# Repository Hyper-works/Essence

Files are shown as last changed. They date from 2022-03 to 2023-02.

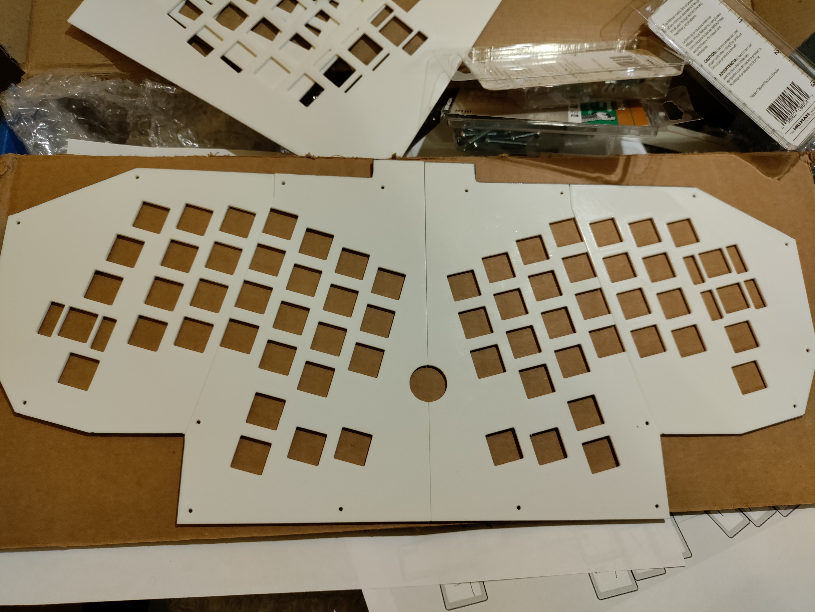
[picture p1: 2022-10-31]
IMG_20220821_130926.jpg

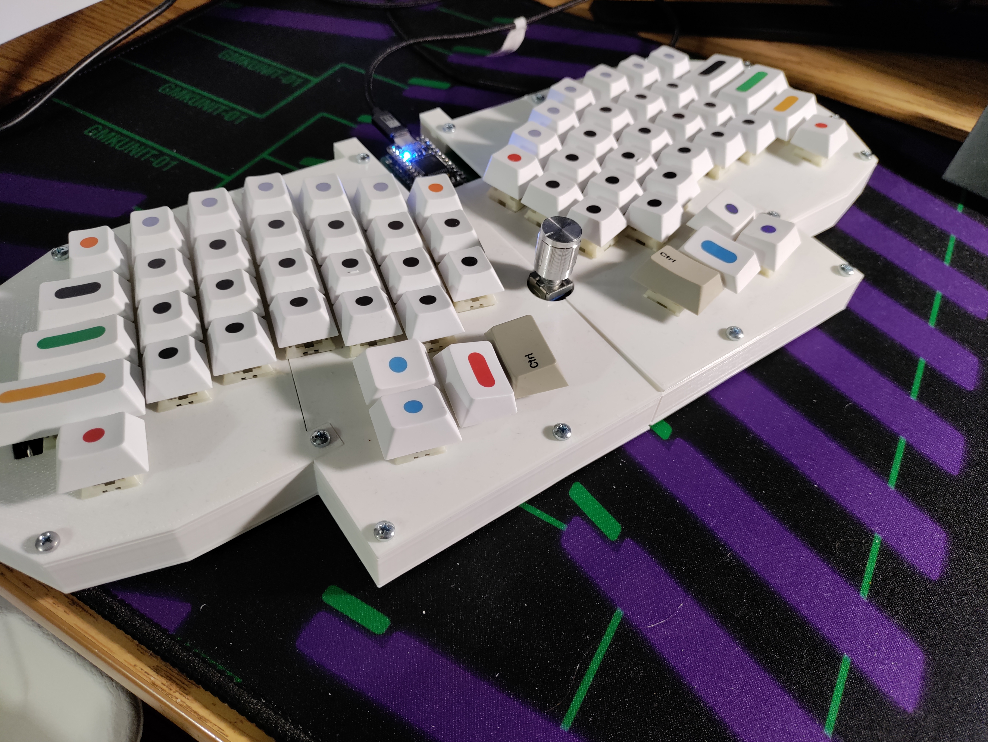
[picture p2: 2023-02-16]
IMG_20230215_195130.jpg

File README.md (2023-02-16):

# Essence
Ergonomic keyboard with standard ANSI Keycaps

Specifications:
64 Key Ergo-Linear keyboard, with customizable rotary encoder

Designed for/powered by the Elite-C Microcontroller board



Parts List:

1 - PCB (Gerber located within this Repository)

1 - Elite-C Microcontroller board: [Found Here](https://keeb.io/collections/diy-parts/products/elite-c-low-profile-version-usb-c-pro-micro-replacement-atmega32u4)

1 - Push switch EC11 Rotary Encoder

1 - Rotary Encoder knob

65 - 1N4148 Diodes (64 for switches, 1 for Encoder switch)

64 - MX style mechanical keyboard switches

64 - MX style keycaps. Specifically:

    48 - 1u keycaps
    
    6 - 1.25u keycaps
    
    5 - 1.5u keycaps
    
    2 - 1.75u keycaps
    
    1 - 2u keycap
    
    2 - 2.25u keycaps
    
3 - 2u MX style key stabilizers

1 - USB-C cable

Also recommended (not technically necessary for keyboard operation):

1 - Switch plate (example provided within this Repository)

1 - Case

.

.

.

.

Explanation and Inspiration:

Originally just a random past time, this project turned into the Senior Project for my High School graduation, and an exploration
of the concepts of PCB design and ergonomics.

My inspiration for this Keyboard design was largely the [Reviung 41](https://github.com/gtips/reviung/tree/master/reviung41), which I daily drove during most of the Covid Lockdown. I fell in
love with the general ergonomics of the board; however, my issues with it became apparent over time:

1.  It doesn't have a number row. Purely for typing and programming, this was a non-issue. I still use the board for both of these
    tasks and love it. But for the games that I do indeed play every now and then, this becomes problematic. A design very similar
    to the Reviung, just with an extra number row, would be great.
   
2.  The keys are all 1 unit, meaning non-standard modifier keys, and difficulty finding keysets. For the Reviung, this was less of
    issue since there were so few modifiers. But with the design I intended to create, this would need to be a consideration, lest
    I spend much more than a kid-with-no-job-at-the-time can afford.

The result, after lots of bumbling around and mistakes, is something I call the Essence.
A unibody, split ergo-linear keyboard powered by an Elite-C Microcontroller board!

keycap_effective

The pre-production key layout. Notice the absence of a Rotary Encoder, which was added later and as such caused more headache
than anticipated.



A failed attempt at prototyping the design of the circuit a 3d-printed jig holding wires to create the key matrix. 3d-printing
would return after the PCB was created



The Essence Circuit Board. In hindsight, the choice for design was a little...bizarre, but this can be amended in KiCad if desired.

.

.

.

This keyboard is still a work in progress, and has many things that can be fixed. I am content with
the current iteration of this board (it works after all), but there are still improvements that can be made.

.

The current fix list:

-The circuit board in general is huge, with lots of deadspace.

-Holes for the right-side stabilizers need to be amended for clearence issues.

-LEDs for thumb cluster modifiers could be incredibly useful.

-A unified case would provide better confidence in its long-term durability.

.

If you have any interest in this board, understand that it is far from perfect. However, if the concept interests you,
go ahead and take a look! Hobbies are fun, especially when they teach you something about how the world works.

Do, no evil

--Hyper-works (Aiden)

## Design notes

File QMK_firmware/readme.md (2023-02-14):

# essence

essence

A 64 key ergolinear keyboard designed to use standard Qwerty keycaps.

* Keyboard Maintainer: [AFerguson](https://github.com/Hyper-works)
* Hardware Supported: Essence keyboard, powered by Elite-c controller board
* Hardware Availability: [Keyboard;](https://github.com/Hyper-works/Essence) and [Control board](https://keeb.io/collections/diy-parts/products/elite-c-low-profile-version-usb-c-pro-micro-replacement-atmega32u4)

Make example for this keyboard (after setting up your build environment):

    make essence:default

Flashing example for this keyboard:

    make essence:default:flash

See the [build environment setup](https://docs.qmk.fm/#/getting_started_build_tools) and the [make instructions](https://docs.qmk.fm/#/getting_started_make_guide) for more information. Brand new to QMK? Start with our [Complete Newbs Guide](https://docs.qmk.fm/#/newbs).

## Bootloader

Enter the bootloader in 3 ways:

* **Bootmagic reset**: Hold down the key at (0,0) in the matrix (usually the top left key or Escape) and plug in the keyboard
* **Physical reset button**: Briefly press the button on the back of the PCB (Built in on Elite-C) - some may have pads you must short instead 
* **Keycode in layout**: Press the key mapped to `QK_BOOT` if it is available

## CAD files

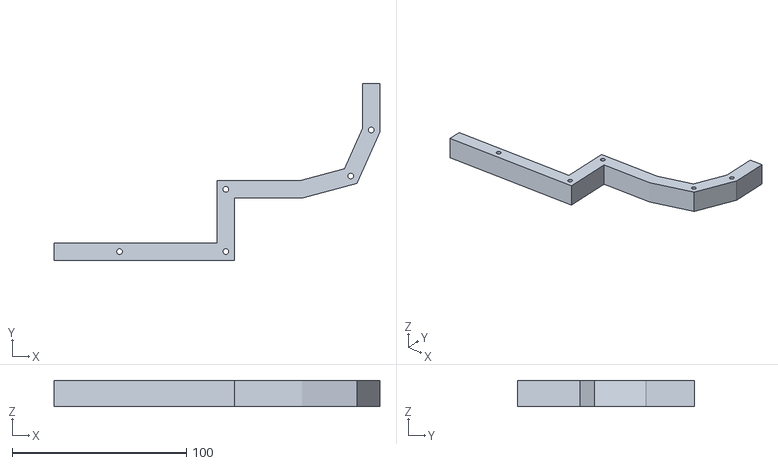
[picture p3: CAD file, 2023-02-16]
Case Files/Perimeters/Right bottom perimeter.stl
187.2 x 101.4 x 15.0

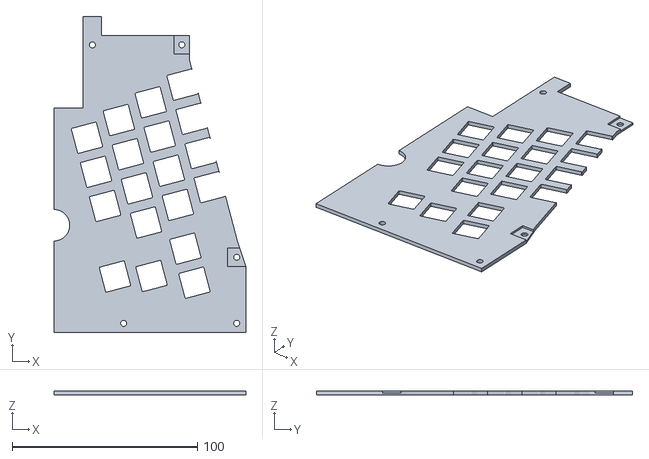
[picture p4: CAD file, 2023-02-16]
Case Files/Plates/Right c.stl
103.7 x 170.8 x 2.00

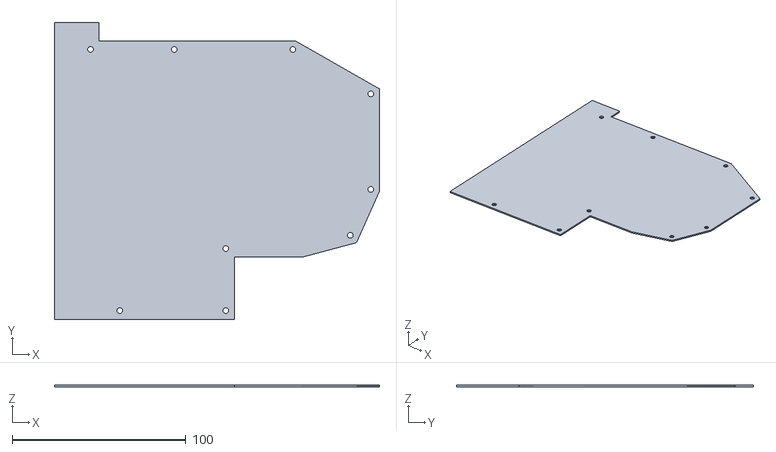
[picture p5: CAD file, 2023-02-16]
Case Files/Plates/Bottom plate right.stl
187.2 x 170.8 x 1.00

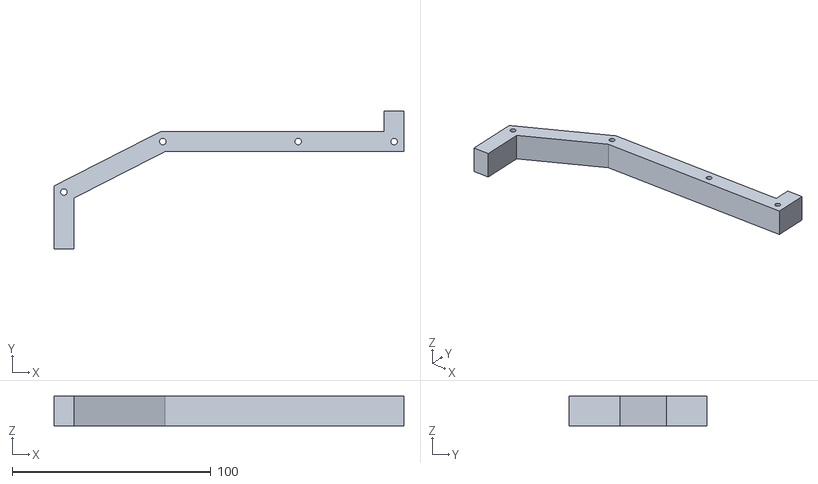
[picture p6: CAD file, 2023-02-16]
Case Files/Perimeters/Left top perimeter.stl
176.3 x 69.5 x 15.0

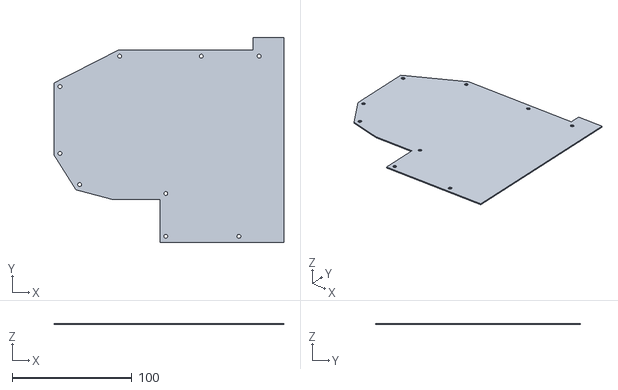
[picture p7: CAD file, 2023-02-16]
Case Files/Plates/Bottom plate left.stl
192.0 x 170.8 x 1.00

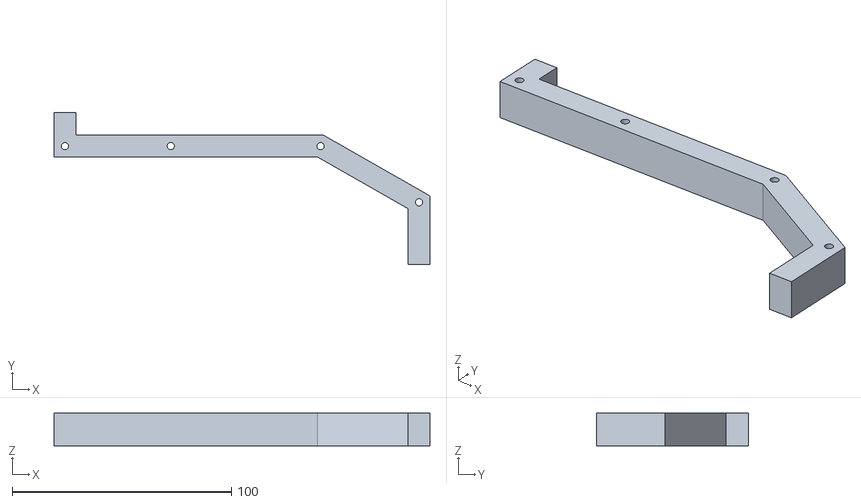
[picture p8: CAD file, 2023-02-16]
Case Files/Perimeters/Right top perimeter.stl
171.5 x 69.4 x 15.0

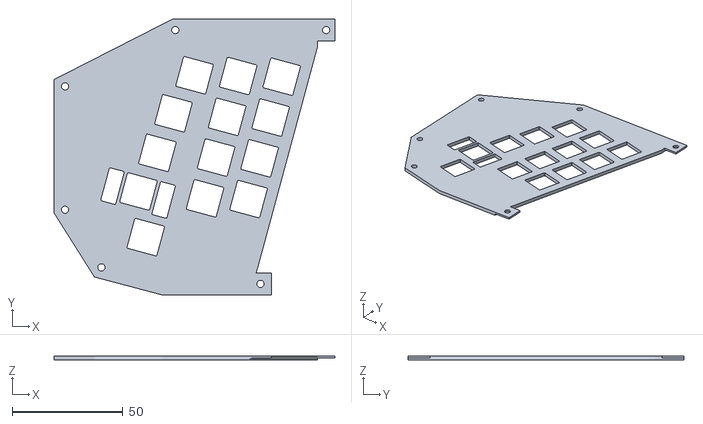
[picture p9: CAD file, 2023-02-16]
Case Files/Plates/Left most.stl
127.0 x 124.7 x 2.00

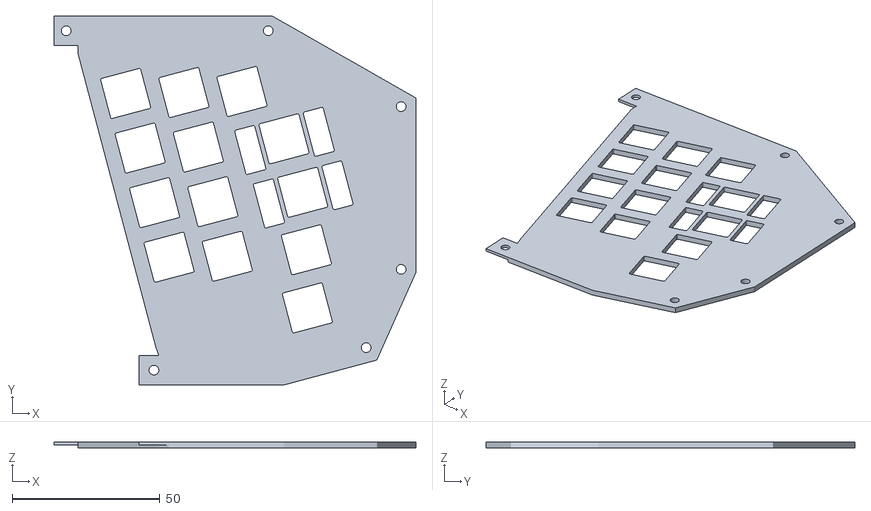
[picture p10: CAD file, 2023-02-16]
Case Files/Plates/Right most.stl
122.3 x 124.7 x 2.00

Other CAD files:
Case Files/Perimeters/Left bottom perimeter.stl
Case Files/Plates/Left c.stl
Case Files/Essence_unified_cad.f3d

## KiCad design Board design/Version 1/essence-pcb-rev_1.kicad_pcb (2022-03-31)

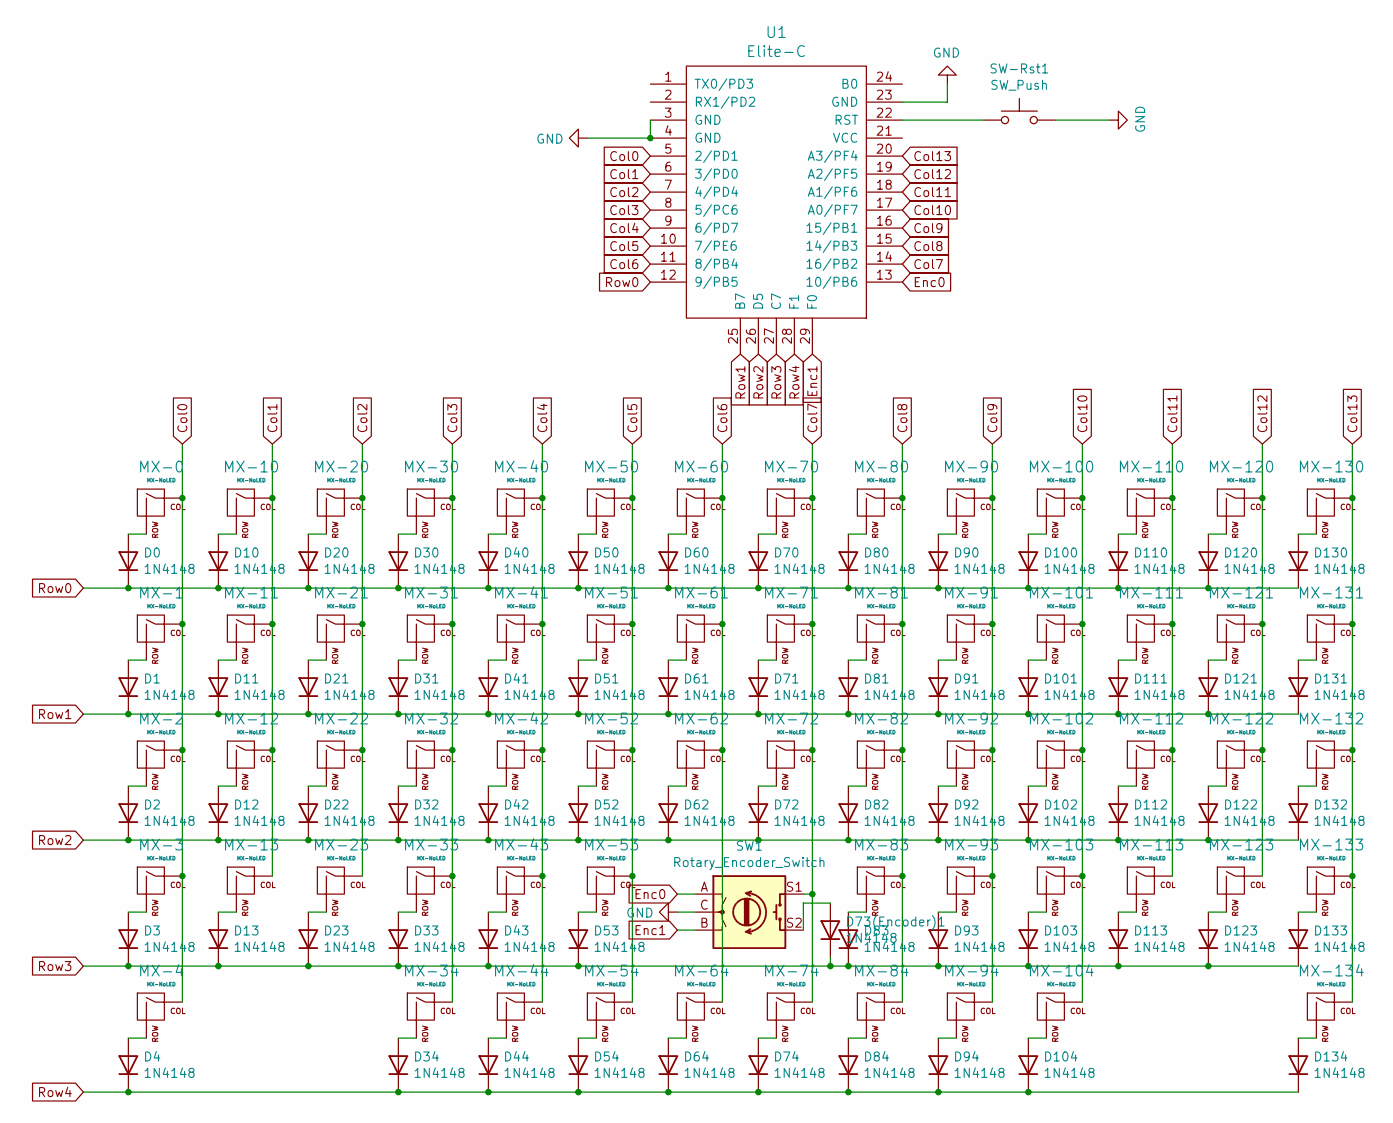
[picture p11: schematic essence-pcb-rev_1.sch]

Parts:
D0, D1, D2, D3, D4, D10, D11, D12, D13, D20, D21, D22, D23, D30, D31, D32, D33, D34, D40, D41, D42, D43, D44, D50, D51, D52, D53, D54, D60, D61, D62, D64, D70, D71, D72, D73(Encoder)1, D74, D80, D81, D82, D83, D84, D90, D91, D92, D93, D94, D100, D101, D102, D103, D104, D110, D111, D112, D113, D120, D121, D122, D123, D130, D131, D132, D133, D134: 1N4148; D_DO-35_SOD27_P7.62mm_Horizontal
MX-0, MX-10, MX-11, MX-12, MX-13, MX-20, MX-21, MX-22, MX-23, MX-30, MX-31, MX-32, MX-33, MX-40, MX-41, MX-42, MX-43, MX-50, MX-51, MX-52, MX-53, MX-60, MX-61, MX-62, MX-70, MX-71, MX-72, MX-80, MX-81, MX-82, MX-83, MX-90, MX-91, MX-92, MX-93, MX-100, MX-101, MX-102, MX-103, MX-110, MX-111, MX-112, MX-113, MX-120, MX-121, MX-122, MX-123, MX-130: MX-NoLED; MX-1U-NoLED
MX-1: MX-NoLED; MX-1.5U-NoLED
MX-2, MX-133: MX-NoLED; MX-1.75U-NoLED
MX-3, MX-132: MX-NoLED; MX-2.25U-NoLED
MX-4, MX-34, MX-44, MX-94, MX-104, MX-134: MX-NoLED; MX-1.25U-NoLED
MX-54, MX-64, MX-74, MX-84: MX-NoLED; MX-1.5U-Vertical
MX-131: MX-NoLED; MX-2U-NoLED
SW1: Rotary_Encoder_Switch; RotaryEncoder_Alps_EC11E-Switch_Vertical_H20mm
SW-Rst1: SW_Push; SW_Tactile_SPST_Angled_MJTP1117
U1: Elite-C; Elite-C-castellated-29pin-holes

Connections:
Col0: MX-0.1 (COL), MX-1.1 (COL), MX-2.1 (COL), MX-3.1 (COL), MX-4.1 (COL), U1.5 (2/PD1)
Col1: MX-10.1 (COL), MX-11.1 (COL), MX-12.1 (COL), MX-13.1 (COL), U1.6 (3/PD0)
Col2: MX-20.1 (COL), MX-21.1 (COL), MX-22.1 (COL), MX-23.1 (COL), U1.7 (4/PD4)
Col3: MX-30.1 (COL), MX-31.1 (COL), MX-32.1 (COL), MX-33.1 (COL), MX-34.1 (COL), U1.8 (5/PC6)
Col4: MX-40.1 (COL), MX-41.1 (COL), MX-42.1 (COL), MX-43.1 (COL), MX-44.1 (COL), U1.9 (6/PD7)
Col5: MX-50.1 (COL), MX-51.1 (COL), MX-52.1 (COL), MX-53.1 (COL), MX-54.1 (COL), U1.10 (7/PE6)
Col6: MX-60.1 (COL), MX-61.1 (COL), MX-62.1 (COL), MX-64.1 (COL), U1.11 (8/PB4)
Col7: MX-70.1 (COL), MX-71.1 (COL), MX-72.1 (COL), MX-74.1 (COL), SW1.S1, U1.14 (16/PB2)
Col8: MX-80.1 (COL), MX-81.1 (COL), MX-82.1 (COL), MX-83.1 (COL), MX-84.1 (COL), U1.15 (14/PB3)
Col9: MX-90.1 (COL), MX-91.1 (COL), MX-92.1 (COL), MX-93.1 (COL), MX-94.1 (COL), U1.16 (15/PB1)
Col10: MX-100.1 (COL), MX-101.1 (COL), MX-102.1 (COL), MX-103.1 (COL), MX-104.1 (COL), U1.17 (A0/PF7)
Col11: MX-110.1 (COL), MX-111.1 (COL), MX-112.1 (COL), MX-113.1 (COL), U1.18 (A1/PF6)
Col12: MX-120.1 (COL), MX-121.1 (COL), MX-122.1 (COL), MX-123.1 (COL), U1.19 (A2/PF5)
Col13: MX-130.1 (COL), MX-131.1 (COL), MX-132.1 (COL), MX-133.1 (COL), MX-134.1 (COL), U1.20 (A3/PF4)
Enc0: SW1.A, U1.13 (10/PB6)
Enc1: SW1.B, U1.29 (F0)
GND: SW1.C, SW-Rst1.2, U1.3 (GND), U1.4 (GND), U1.23 (GND)
unnamed: D0.2 (A), MX-0.2 (ROW)
unnamed: D1.2 (A), MX-1.2 (ROW)
unnamed: D2.2 (A), MX-2.2 (ROW)
unnamed: D3.2 (A), MX-3.2 (ROW)
unnamed: D4.2 (A), MX-4.2 (ROW)
unnamed: D10.2 (A), MX-10.2 (ROW)
unnamed: D11.2 (A), MX-11.2 (ROW)
unnamed: D12.2 (A), MX-12.2 (ROW)
unnamed: D13.2 (A), MX-13.2 (ROW)
unnamed: D20.2 (A), MX-20.2 (ROW)
unnamed: D21.2 (A), MX-21.2 (ROW)
unnamed: D22.2 (A), MX-22.2 (ROW)
unnamed: D23.2 (A), MX-23.2 (ROW)
unnamed: D30.2 (A), MX-30.2 (ROW)
unnamed: D31.2 (A), MX-31.2 (ROW)
unnamed: D32.2 (A), MX-32.2 (ROW)
unnamed: D33.2 (A), MX-33.2 (ROW)
unnamed: D34.2 (A), MX-34.2 (ROW)
unnamed: D40.2 (A), MX-40.2 (ROW)
unnamed: D41.2 (A), MX-41.2 (ROW)
unnamed: D42.2 (A), MX-42.2 (ROW)
unnamed: D43.2 (A), MX-43.2 (ROW)
unnamed: D44.2 (A), MX-44.2 (ROW)
unnamed: D50.2 (A), MX-50.2 (ROW)
unnamed: D51.2 (A), MX-51.2 (ROW)
unnamed: D52.2 (A), MX-52.2 (ROW)
unnamed: D53.2 (A), MX-53.2 (ROW)
unnamed: D54.2 (A), MX-54.2 (ROW)
unnamed: D60.2 (A), MX-60.2 (ROW)
unnamed: D61.2 (A), MX-61.2 (ROW)
unnamed: D62.2 (A), MX-62.2 (ROW)
unnamed: D64.2 (A), MX-64.2 (ROW)
unnamed: D70.2 (A), MX-70.2 (ROW)
unnamed: D71.2 (A), MX-71.2 (ROW)
unnamed: D72.2 (A), MX-72.2 (ROW)
unnamed: D73(Encoder)1.2 (A), SW1.S2
unnamed: D74.2 (A), MX-74.2 (ROW)
unnamed: D80.2 (A), MX-80.2 (ROW)
unnamed: D81.2 (A), MX-81.2 (ROW)
unnamed: D82.2 (A), MX-82.2 (ROW)
unnamed: D83.2 (A), MX-83.2 (ROW)
unnamed: D84.2 (A), MX-84.2 (ROW)
unnamed: D90.2 (A), MX-90.2 (ROW)
unnamed: D91.2 (A), MX-91.2 (ROW)
unnamed: D92.2 (A), MX-92.2 (ROW)
unnamed: D93.2 (A), MX-93.2 (ROW)
unnamed: D94.2 (A), MX-94.2 (ROW)
unnamed: D100.2 (A), MX-100.2 (ROW)
unnamed: D101.2 (A), MX-101.2 (ROW)
unnamed: D102.2 (A), MX-102.2 (ROW)
unnamed: D103.2 (A), MX-103.2 (ROW)
unnamed: D104.2 (A), MX-104.2 (ROW)
unnamed: D110.2 (A), MX-110.2 (ROW)
unnamed: D111.2 (A), MX-111.2 (ROW)
unnamed: D112.2 (A), MX-112.2 (ROW)
unnamed: D113.2 (A), MX-113.2 (ROW)
unnamed: D120.2 (A), MX-120.2 (ROW)
unnamed: D121.2 (A), MX-121.2 (ROW)
unnamed: D122.2 (A), MX-122.2 (ROW)
unnamed: D123.2 (A), MX-123.2 (ROW)
unnamed: D130.2 (A), MX-130.2 (ROW)
unnamed: D131.2 (A), MX-131.2 (ROW)
unnamed: D132.2 (A), MX-132.2 (ROW)
unnamed: D133.2 (A), MX-133.2 (ROW)
unnamed: D134.2 (A), MX-134.2 (ROW)
unnamed: SW-Rst1.1, U1.22 (RST)
Row0: D0.1 (K), D10.1 (K), D20.1 (K), D30.1 (K), D40.1 (K), D50.1 (K), D60.1 (K), D70.1 (K), D80.1 (K), D90.1 (K), D100.1 (K), D110.1 (K), D120.1 (K), D130.1 (K), U1.12 (9/PB5)
Row1: D1.1 (K), D11.1 (K), D21.1 (K), D31.1 (K), D41.1 (K), D51.1 (K), D61.1 (K), D71.1 (K), D81.1 (K), D91.1 (K), D101.1 (K), D111.1 (K), D121.1 (K), D131.1 (K), U1.25 (B7)
Row2: D2.1 (K), D12.1 (K), D22.1 (K), D32.1 (K), D42.1 (K), D52.1 (K), D62.1 (K), D72.1 (K), D82.1 (K), D92.1 (K), D102.1 (K), D112.1 (K), D122.1 (K), D132.1 (K), U1.26 (D5)
Row3: D3.1 (K), D13.1 (K), D23.1 (K), D33.1 (K), D43.1 (K), D53.1 (K), D73(Encoder)1.1 (K), D83.1 (K), D93.1 (K), D103.1 (K), D113.1 (K), D123.1 (K), D133.1 (K), U1.27 (C7)
Row4: D4.1 (K), D34.1 (K), D44.1 (K), D54.1 (K), D64.1 (K), D74.1 (K), D84.1 (K), D94.1 (K), D104.1 (K), D134.1 (K), U1.28 (F1)

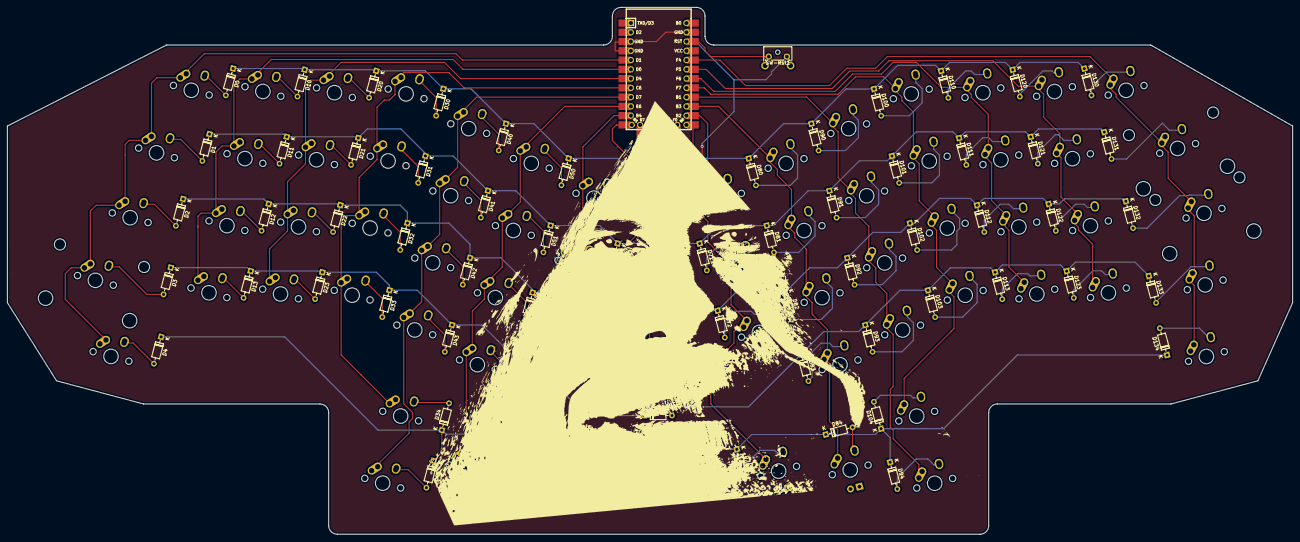
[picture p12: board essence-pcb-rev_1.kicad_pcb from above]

Board: 2 copper layers, 352.4 x 144.5 mm, 132 parts (0 on the bottom side), 88 nets.

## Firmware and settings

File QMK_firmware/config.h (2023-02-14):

// Copyright 2022 Aiden (@Hyper-works)
// SPDX-License-Identifier: GPL-2.0-or-later

#pragma once

#include "config_common.h"

/*key matrix*/
#define MATRIX_ROWS 5
#define MATRIX_COLS 14

#define MATRIX_COL_PINS { D1, D0, D4, C6, D7, E6, B4, B2, B3, B1, F7, F6, F5, F4 }
#define MATRIX_ROW_PINS { B5, B7, D5, C7, F1 }
#define DIODE_DIRECTION COL2ROW

/*encoder*/
#define ENCODERS_PAD_A { F0 }
#define ENCODERS_PAD_B { B6 }
#define ENCODER_RESOLUTION 2

/*
 * Feature disable options
 *  These options are also useful to firmware size reduction.
 */

/* disable debug print */
//#define NO_DEBUG

/* disable print */
//#define NO_PRINT

/* disable action features */
//#define NO_ACTION_LAYER
//#define NO_ACTION_TAPPING
//#define NO_ACTION_ONESHOT

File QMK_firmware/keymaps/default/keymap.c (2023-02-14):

#include QMK_KEYBOARD_H

enum layers {
    BASE,
    FN,
    MED,
};

const uint16_t PROGMEM keymaps[][MATRIX_ROWS][MATRIX_COLS] = {
    /*
     * ┌───┬───┬───┬───┐
     * │ 7 │ 8 │ 9 │ / │
     * ├───┼───┼───┼───┤
     * │ 4 │ 5 │ 6 │ * │
     * ├───┼───┼───┼───┤
     * │ 1 │ 2 │ 3 │ - │
     * ├───┼───┼───┼───┤
     * │ 0 │ . │Ent│ + │
     * └───┴───┴───┴───┘
     * KC_BSLS
     */
    [BASE] = LAYOUT_essence(
        KC_ESC,    KC_1,   KC_2,   KC_3,    KC_4,    KC_5,   KC_GRAVE, KC_EQUAL, KC_6,    KC_7,    KC_8,    KC_9,   KC_0,    KC_MINUS,
        KC_TAB,    KC_Q,   KC_W,   KC_E,    KC_R,    KC_T,   KC_LBRC,  KC_RBRC,  KC_Y,    KC_U,    KC_I,    KC_O,   KC_P,    KC_BSPC,
        KC_CAPS,   KC_A,   KC_S,   KC_D,    KC_F,    KC_G,   KC_BSLS,  KC_QUOT,  KC_H,    KC_J,    KC_K,    KC_L,   KC_SCLN, KC_ENT,
        KC_LSFT,   KC_Z,   KC_X,   KC_C,    KC_V,    KC_B,             KC_MPLY,  KC_N,    KC_M,    KC_COMM, KC_DOT, KC_SLSH, KC_RSFT,
        KC_LCTL,                   MO(FN),  KC_LALT, KC_SPC, KC_F13,   KC_F14,   KC_RSFT, KC_RWIN, TG(MED),                  KC_RCTL
    ),

    [FN] = LAYOUT_essence(
        _______,  KC_F1,   KC_F2,   KC_F3,   KC_F4,   KC_F5,   KC_F6,   KC_F7,   KC_F8,   KC_F9,   KC_F10,  KC_F11,  KC_F12, _______,
        _______, _______, _______, _______, _______, _______, _______, _______, _______, _______, _______, _______, _______, _______,
        _______, _______, _______, _______, _______, _______, _______, _______, _______, _______, _______, _______, _______, KC_SLEP,
        _______, _______, _______, _______, _______, _______,          _______, _______, _______, _______, _______, _______, _______,
        _______,                   _______, _______, _______, _______, _______, _______, _______,   KC_NO,                   _______
        ),

    [MED] = LAYOUT_essence(
        _______, _______, _______, _______, _______, _______, _______, _______, _______, _______, _______, _______, _______, _______,
        _______, _______, _______, _______, _______, _______, _______, _______, _______, _______,  KC_UP,  _______, _______, _______,
        _______, _______, _______, _______, _______, _______, KC_MPRV, KC_MNXT, _______, KC_LEFT, KC_DOWN, KC_RGHT, _______, _______,
        _______, _______, _______, _______, _______, _______,          _______, _______, _______, _______, _______, _______, _______,
        _______,                   _______, _______, _______, _______, _______, _______, _______, _______,                   _______
        )
};

#if defined(ENCODER_MAP_ENABLE)
const uint16_t PROGMEM encoder_map[][NUM_ENCODERS][2] = {
    [BASE] =   { ENCODER_CCW_CW(KC_VOLD, KC_VOLU)  },
    [FN] =  { ENCODER_CCW_CW(_______, _______)  },
    [MED] =  { ENCODER_CCW_CW(_______, _______)  },
};
#endif

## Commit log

2021-08-07 File creation
    [stergo_mod0.kicad_pcb, stergo_mod0.sch]
2021-08-07 Footprint Configuration
2022-01-30 elite c footprint in schematic
    I now realize that I have no idea how to wire up a daughter board on a keyboard. To Reddit I go...
    [essence-pcb-rev_1.sch]
2022-02-06 Schematic layout
    I think I did this right using the Elite-C footprint, but I do not know. Good thing PCBs are cheap to make...kind of
    [essence-pcb-rev_1.sch]
2022-02-07 Annotations for schematic components
    I now need to look for a footprint for the Rotary Encoder, although I think I found it off of the KiCad Subreddit. If you are reading this for some reason, random person, go make a sandwich.
    [essence-pcb-rev_1.sch]
2022-02-07 Possible Encoder footprint
2022-02-07 Possibly added footprints?
2022-02-21 Found Rotary Encoder symbol
    Why was this so damn difficult to find in KiCad's default libraries? The world may never know...
    [essence-pcb-rev_1.sch]
2022-02-22 Rotary Encoder Slotted into Schematic
    [essence-pcb-rev_1.sch]
2022-02-22 Footprints assigned in schematic
    [essence-pcb-rev_1.sch]
2022-02-22 Temporary PCB save
    [essence-pcb-rev_1.kicad_pcb]
2022-02-24 More PCB progress
    [essence-pcb-rev_1.kicad_pcb]
2022-02-25 Temporary key grid made
    [essence-pcb-rev_1.kicad_pcb]
2022-02-25 Ergolinear format for left side
    [essence-pcb-rev_1.kicad_pcb]
2022-02-25 Non-tented layout finished
    [essence-pcb-rev_1.kicad_pcb]
2022-02-25 Diode proximity established
    [essence-pcb-rev_1.kicad_pcb]
2022-02-26 PCB tent integrated
    For some reason, multi-footprint rotate is located in the move window? If you are reading this go make a milkshake
    [essence-pcb-rev_1.kicad_pcb]
2022-02-26 Elite C positioned in center
    This may be changed depending on cable position preferences, will sleep on it.
    [essence-pcb-rev_1.kicad_pcb]
2022-03-19 Board Outline made
    [essence-pcb-rev_1.kicad_pcb]
2022-03-20 Initial routing pattern
    [essence-pcb-rev_1.kicad_pcb]
2022-03-20 Updated pin placement on Elite C to matrix
    [essence-pcb-rev_1.kicad_pcb, essence-pcb-rev_1.sch]
2022-03-20 Track Rough Draft (all connected, edit needed)
    [essence-pcb-rev_1.kicad_pcb]
2022-03-20 Final Routing
    [essence-pcb-rev_1.kicad_pcb]
2022-03-20 Reset Switch added, and Ground fields defined
    I think I outlined the ground fields correctly, but I will get input to be sure before I manufacture it
    [essence-pcb-rev_1.kicad_pcb, essence-pcb-rev_1.sch]
2022-03-20 PCB graphics
    [essence-pcb-rev_1.kicad_pcb]
2022-03-20 Gerbers generated
    [essence-pcb-rev_1-B_Cu.gbl, essence-pcb-rev_1-B_Mask.gbs, essence-pcb-rev_1-B_Paste.gbp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]
2022-03-20 Final Commit Mayber?
    [essence-pcb-rev_1.kicad_pcb]
2022-03-31 Various actions made to create plates
    [essence-pcb-rev_1-B_Cu.gbl, essence-pcb-rev_1-B_Mask.gbs, essence-pcb-rev_1-B_Paste.gbp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]
2023-02-16 Organized the Repository
    [essence-pcb-rev_1-B_Cu.gbl, essence-pcb-rev_1-B_Mask.gbs, essence-pcb-rev_1-B_Paste.gbp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]
2023-02-16 Added Case Files
    [Bottom plate left.stl, Bottom plate right.stl, Essence_unified_cad.f3d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]
